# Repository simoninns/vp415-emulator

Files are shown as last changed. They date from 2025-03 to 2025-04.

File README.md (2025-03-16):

# VP415 Emulator
## Project status
This is a purely experimental repo and is not for any kind of production use.

## Disclaimer
Whatever is in this repository is fiction and should not be taken seriously. All similarities with real world designs and coding was not intentional

## Author
VP415 Emulator is designed and maintained by Simon Inns.

## Software License (GPLv3)

    This is free software: you can redistribute it and/or modify
    it under the terms of the GNU General Public License as published by
    the Free Software Foundation, either version 3 of the License, or
    (at your option) any later version.

    This software is distributed in the hope that it will be useful,
    but WITHOUT ANY WARRANTY; without even the implied warranty of
    MERCHANTABILITY or FITNESS FOR A PARTICULAR PURPOSE.  See the
    GNU General Public License for more details.

    You should have received a copy of the GNU General Public License
    along with this program.  If not, see <http://www.gnu.org/licenses/>.

## Hardware License (Creative Commons BY-SA 4.0)
Please see the following link for details: https://creativecommons.org/licenses/by-sa/4.0/

You are free to:

Share - copy and redistribute the material in any medium or format
Adapt - remix, transform, and build upon the material
for any purpose, even commercially.

This license is acceptable for Free Cultural Works.

The licensor cannot revoke these freedoms as long as you follow the license terms.

Under the following terms:

Attribution - You must give appropriate credit, provide a link to the license, and indicate if changes were made. You may do so in any reasonable manner, but not in any way that suggests the licensor endorses you or your use.

ShareAlike - If you remix, transform, or build upon the material, you must distribute your contributions under the same license as the original.

No additional restrictions - You may not apply legal terms or technological measures that legally restrict others from doing anything the license permits.

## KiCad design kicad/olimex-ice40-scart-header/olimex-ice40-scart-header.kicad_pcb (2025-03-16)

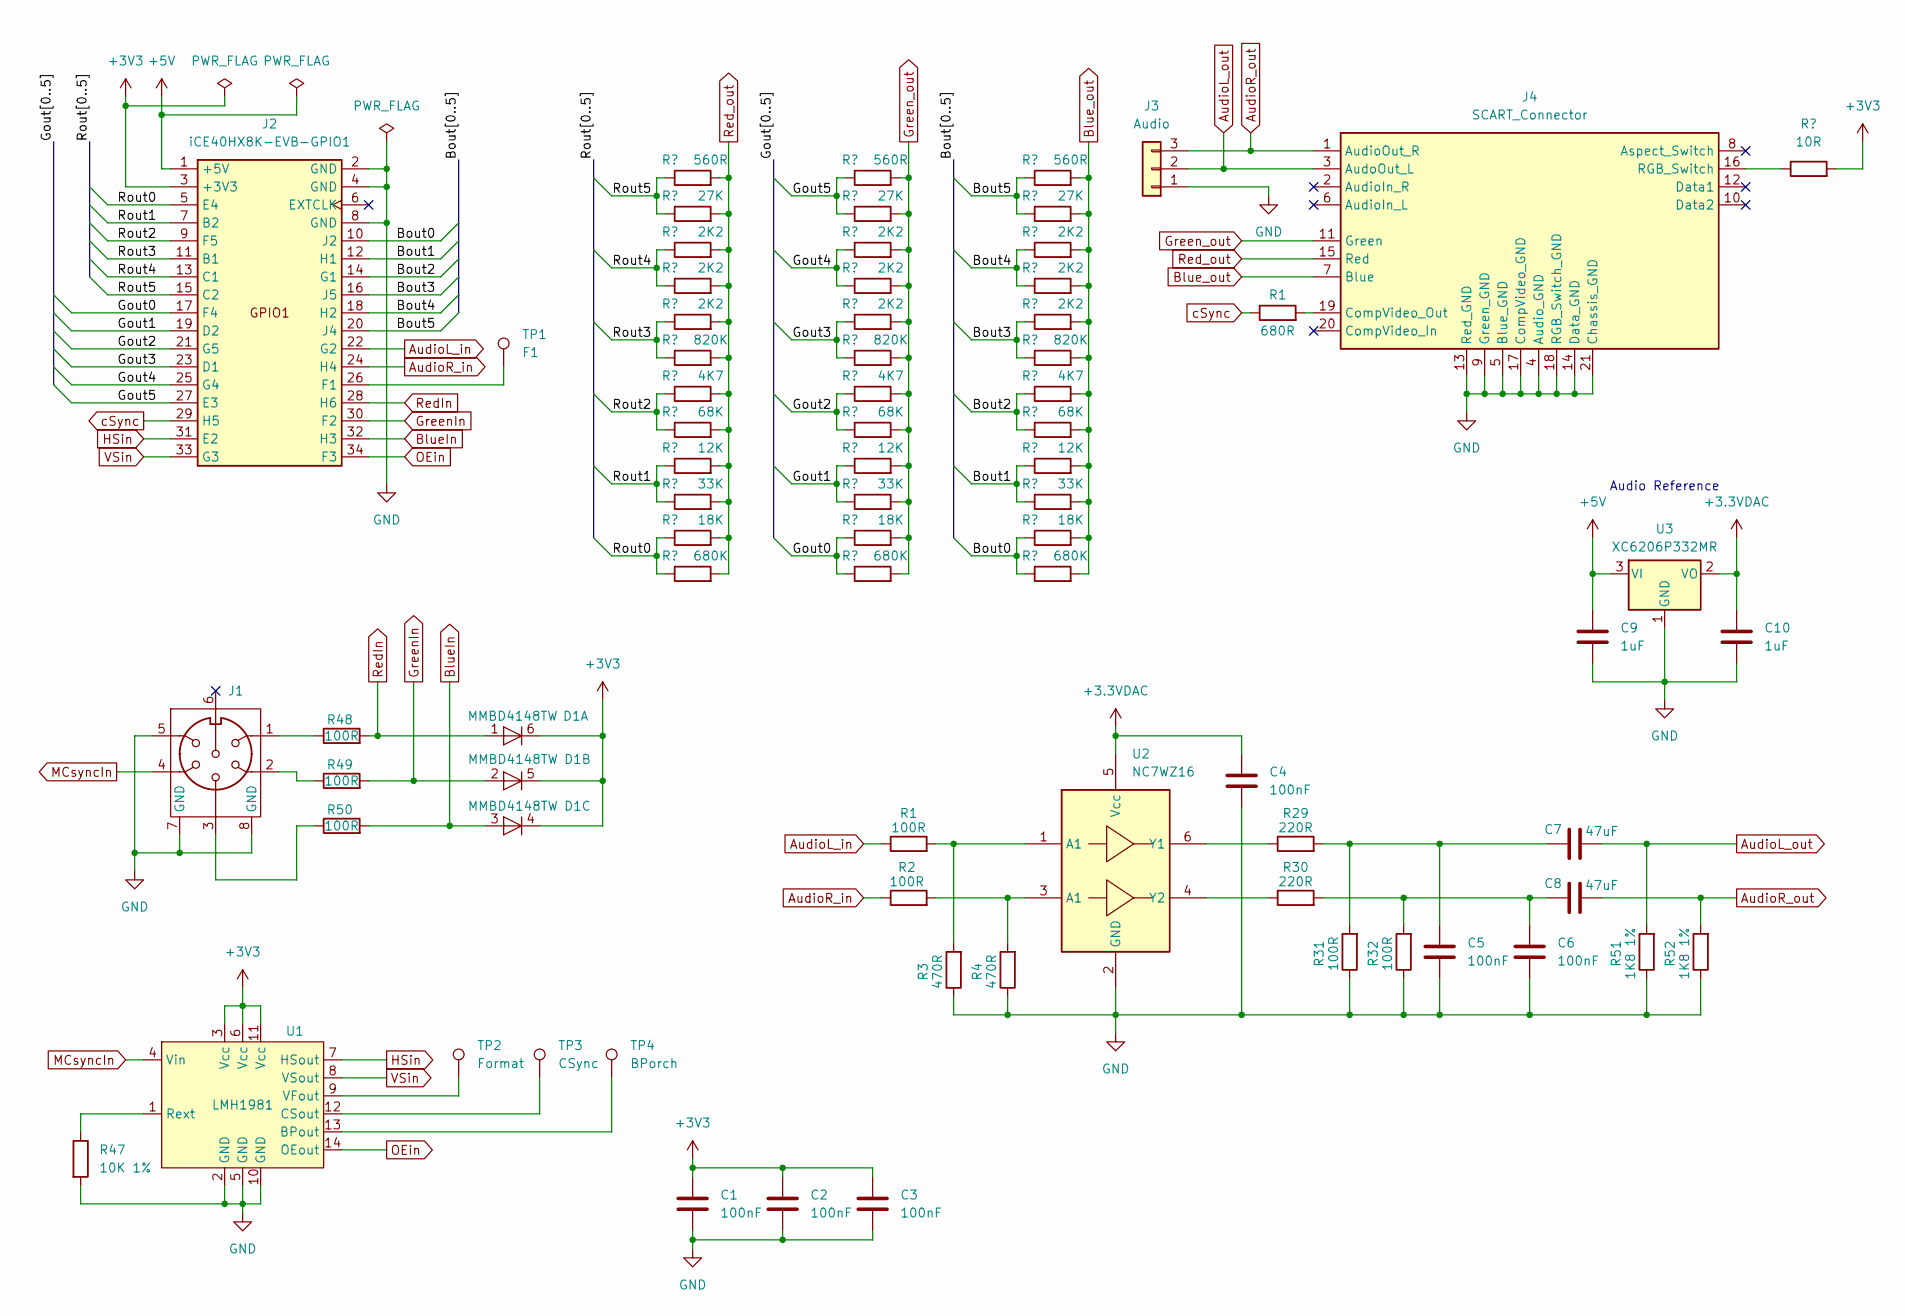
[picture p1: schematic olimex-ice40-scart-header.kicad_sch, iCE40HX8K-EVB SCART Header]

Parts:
C1, C2, C3, C4, C5, C6: 100nF; C_0603_1608Metric_Pad1.08x0.95mm_HandSolder
C7, C8: 47uF; C_0603_1608Metric_Pad1.08x0.95mm_HandSolder
C9, C10: 1uF; C_0603_1608Metric_Pad1.08x0.95mm_HandSolder
D1: MMBD4148TW; SOT-363_SC-70-6
J1: 6P DIN Socket RS Pro
J2: iCE40HX8K-EVB-GPIO1; IDC-Header_2x17_P2.54mm_Horizontal
J3: Audio; PinHeader_1x03_P2.54mm_Vertical
J4: SCART_Connector; HSM_C0381-21RYATB0R
R1: 680R; R_0603_1608Metric_Pad0.98x0.95mm_HandSolder
R2, R31, R32, R48, R49, R50: 100R; R_0603_1608Metric_Pad0.98x0.95mm_HandSolder
R3, R4: 470R; R_0603_1608Metric_Pad0.98x0.95mm_HandSolder
R5, R17, R33: 560R; R_0603_1608Metric_Pad0.98x0.95mm_HandSolder
R6, R18, R34: 27K; R_0603_1608Metric_Pad0.98x0.95mm_HandSolder
R7, R8, R9, R19, R20, R21, R35, R36, R37: 2K2; R_0603_1608Metric_Pad0.98x0.95mm_HandSolder
R10, R22, R38: 820K; R_0603_1608Metric_Pad0.98x0.95mm_HandSolder
R11, R23, R39: 4K7; R_0603_1608Metric_Pad0.98x0.95mm_HandSolder
R12, R24, R40: 68K; R_0603_1608Metric_Pad0.98x0.95mm_HandSolder
R13, R25, R41: 12K; R_0603_1608Metric_Pad0.98x0.95mm_HandSolder
R14, R26, R42: 33K; R_0603_1608Metric_Pad0.98x0.95mm_HandSolder
R15, R27, R43: 18K; R_0603_1608Metric_Pad0.98x0.95mm_HandSolder
R16, R28, R44: 680K; R_0603_1608Metric_Pad0.98x0.95mm_HandSolder
R29, R30: 220R; R_0603_1608Metric_Pad0.98x0.95mm_HandSolder
R46: 10R; R_0603_1608Metric_Pad0.98x0.95mm_HandSolder
R47: 10K 1%; R_0603_1608Metric_Pad0.98x0.95mm_HandSolder
R51, R52: 1K8 1%; R_0603_1608Metric_Pad0.98x0.95mm_HandSolder
TP1: F1; TestPoint_Pad_1.5x1.5mm
TP2: Format; TestPoint_Pad_1.5x1.5mm
TP3: CSync; TestPoint_Pad_1.5x1.5mm
TP4: BPorch; TestPoint_Pad_1.5x1.5mm
U1: LMH1981; TSSOP-14_4.4x5mm_P0.65mm
U2: NC7WZ16; SOT-363_SC-70-6_Handsoldering
U3: XC6206P332MR; SOT-23-3

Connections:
+3.3VDAC: C4.1, C10.1, U2.5 (Vcc), U3.2 (VO)
+3V3: C1.1, C2.1, C3.1, D1.4 (K), D1.5 (K), D1.6 (K), J2.3 (+3V3), R46.2, U1.3 (Vcc), U1.6 (Vcc), U1.11 (Vcc)
+5V: C9.1, J2.1 (+5V), U3.3 (VI)
/Bout0: J2.10 (J2), R43.1, R44.1
/Bout1: J2.12 (H1), R41.1, R42.1
/Bout2: J2.14 (G1), R39.1, R40.1
/Bout3: J2.16 (J5), R37.1, R38.1
/Bout4: J2.18 (H2), R35.1, R36.1
/Bout5: J2.20 (J4), R33.1, R34.1
/Gout0: J2.17 (F4), R27.1, R28.1
/Gout1: J2.19 (D2), R25.1, R26.1
/Gout2: J2.21 (G5), R23.1, R24.1
/Gout3: J2.23 (D1), R21.1, R22.1
/Gout4: J2.25 (G4), R19.1, R20.1
/Gout5: J2.27 (E3), R17.1, R18.1
/Rout0: J2.5 (E4), R15.1, R16.1
/Rout1: J2.7 (B2), R13.1, R14.1
/Rout2: J2.9 (F5), R11.1, R12.1
/Rout3: J2.11 (B1), R9.1, R10.1
/Rout4: J2.13 (C1), R7.1, R8.1
/Rout5: J2.15 (C2), R5.1, R6.1
AudioL_out: C7.2, J3.2, J4.3 (AudoOut_L), R51.2
AudioR_in: J2.24 (H4), R2.1
AudioR_out: C8.2, J3.3, J4.1 (AudioOut_R), R52.2
BlueIn: D1.3 (A), J2.32 (H3), R50.2
Blue_out: J4.7 (Blue), R33.2, R34.2, R35.2, R36.2, R37.2, R38.2, R39.2, R40.2, R41.2, R42.2, R43.2, R44.2
GND: C1.2, C2.2, C3.2, C4.2, C5.2, C6.2, C9.2, C10.2, J1.5, J1.7 (GND), J1.8 (GND), J2.2 (GND), J2.4 (GND), J2.8 (GND), J3.1, J4.4 (Audio_GND), J4.5 (Blue_GND), J4.9 (Green_GND), J4.13 (Red_GND), J4.14 (Data_GND), J4.17 (CompVideo_GND), J4.18 (RGB_Switch_GND), J4.21 (Chassis_GND), R3.1, R4.1, R31.1, R32.1, R47.2, R51.1, R52.1, U1.2 (GND), U1.5 (GND), U1.10 (GND), U2.2 (GND), U3.1 (GND)
GreenIn: D1.2 (A), J2.30 (F2), R49.2
Green_out: J4.11 (Green), R17.2, R18.2, R19.2, R20.2, R21.2, R22.2, R23.2, R24.2, R25.2, R26.2, R27.2, R28.2
HSin: J2.31 (E2), U1.7 (HSout)
MCsyncIn: J1.4, U1.4 (Vin)
unnamed: C5.1, C7.1, R29.2, R31.2
unnamed: C6.1, C8.1, R30.2, R32.2
unnamed: J1.1, R48.1
unnamed: J1.2, R49.1
unnamed: J1.3, R50.1
unnamed: J2.26 (F1), TP1.1
unnamed: J4.16 (RGB_Switch), R46.1
unnamed: R2.2, R4.2, U2.3 (A1)
unnamed: TP4.1, U1.13 (BPout)
unnamed: TP3.1, U1.12 (CSout)
unnamed: R47.1, U1.1 (Rext)
unnamed: TP2.1, U1.9 (VFout)
unnamed: R29.1, U2.6 (Y1)
unnamed: R30.1, U2.4 (Y2)
OEin: J2.34 (F3), U1.14 (OEout)
RedIn: D1.1 (A), J2.28 (H6), R48.2
Red_out: J4.15 (Red), R5.2, R6.2, R7.2, R8.2, R9.2, R10.2, R11.2, R12.2, R13.2, R14.2, R15.2, R16.2
VSin: J2.33 (G3), U1.8 (VSout)

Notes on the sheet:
Audio Reference

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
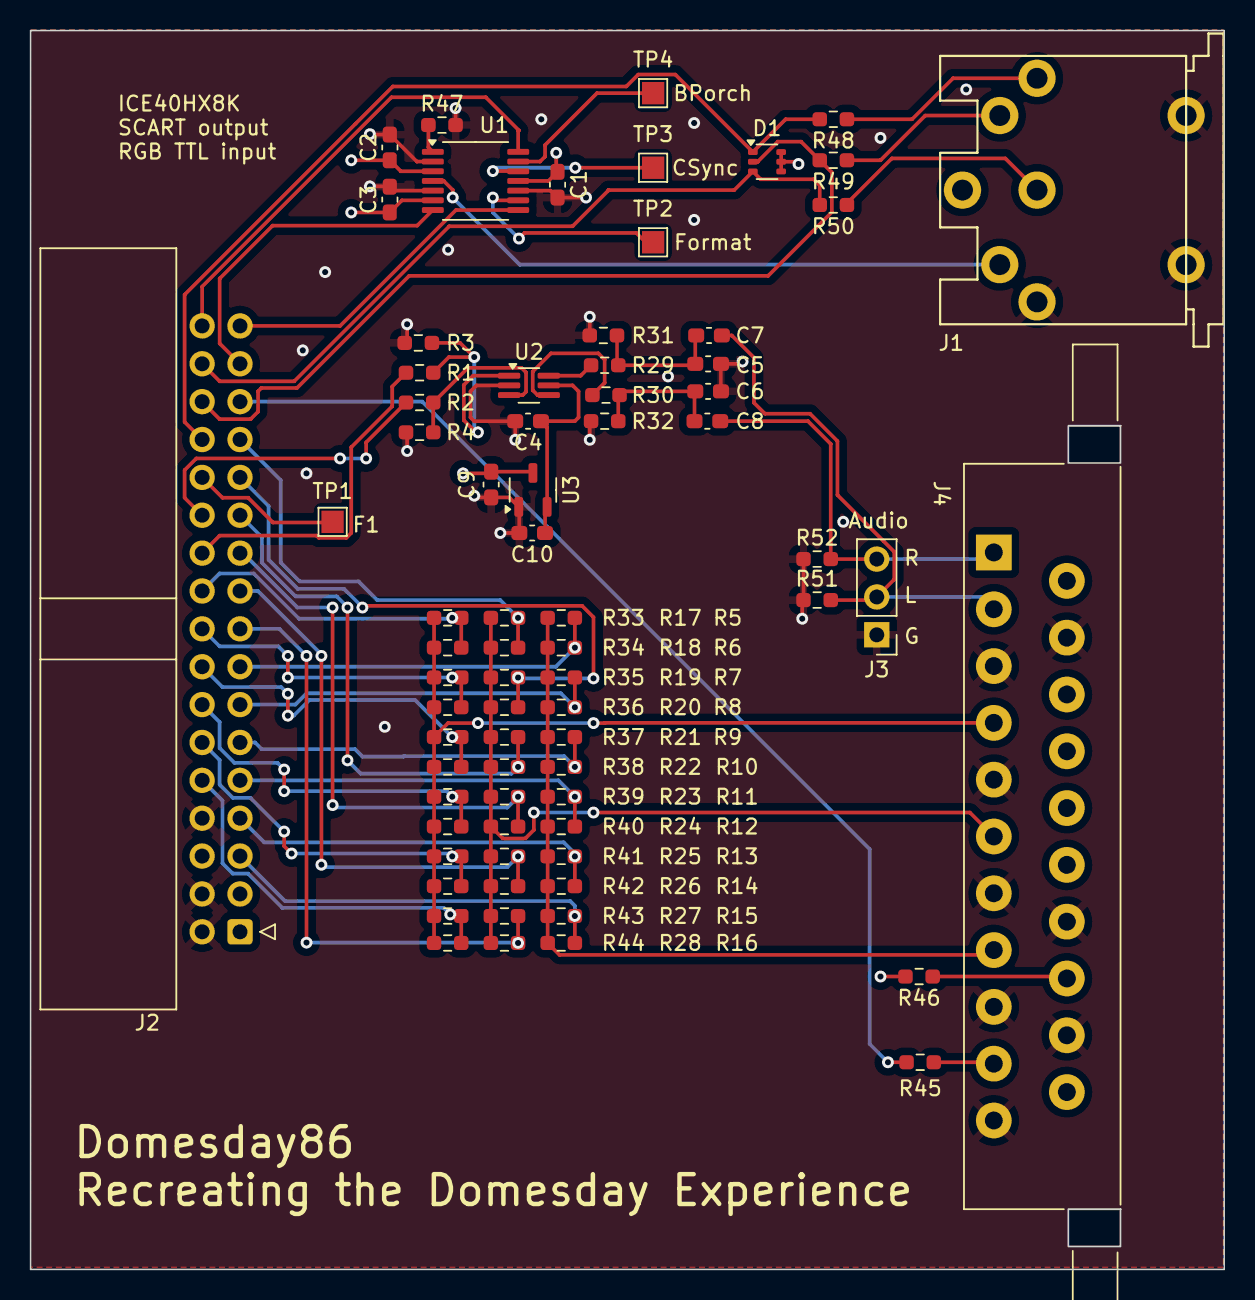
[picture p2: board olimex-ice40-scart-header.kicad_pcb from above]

Board: 4 copper layers, 80.1 x 83.1 mm, 74 parts (0 on the bottom side), 53 nets.

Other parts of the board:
R45: 680R; R_0603_1608Metric_Pad0.98x0.95mm_HandSolder

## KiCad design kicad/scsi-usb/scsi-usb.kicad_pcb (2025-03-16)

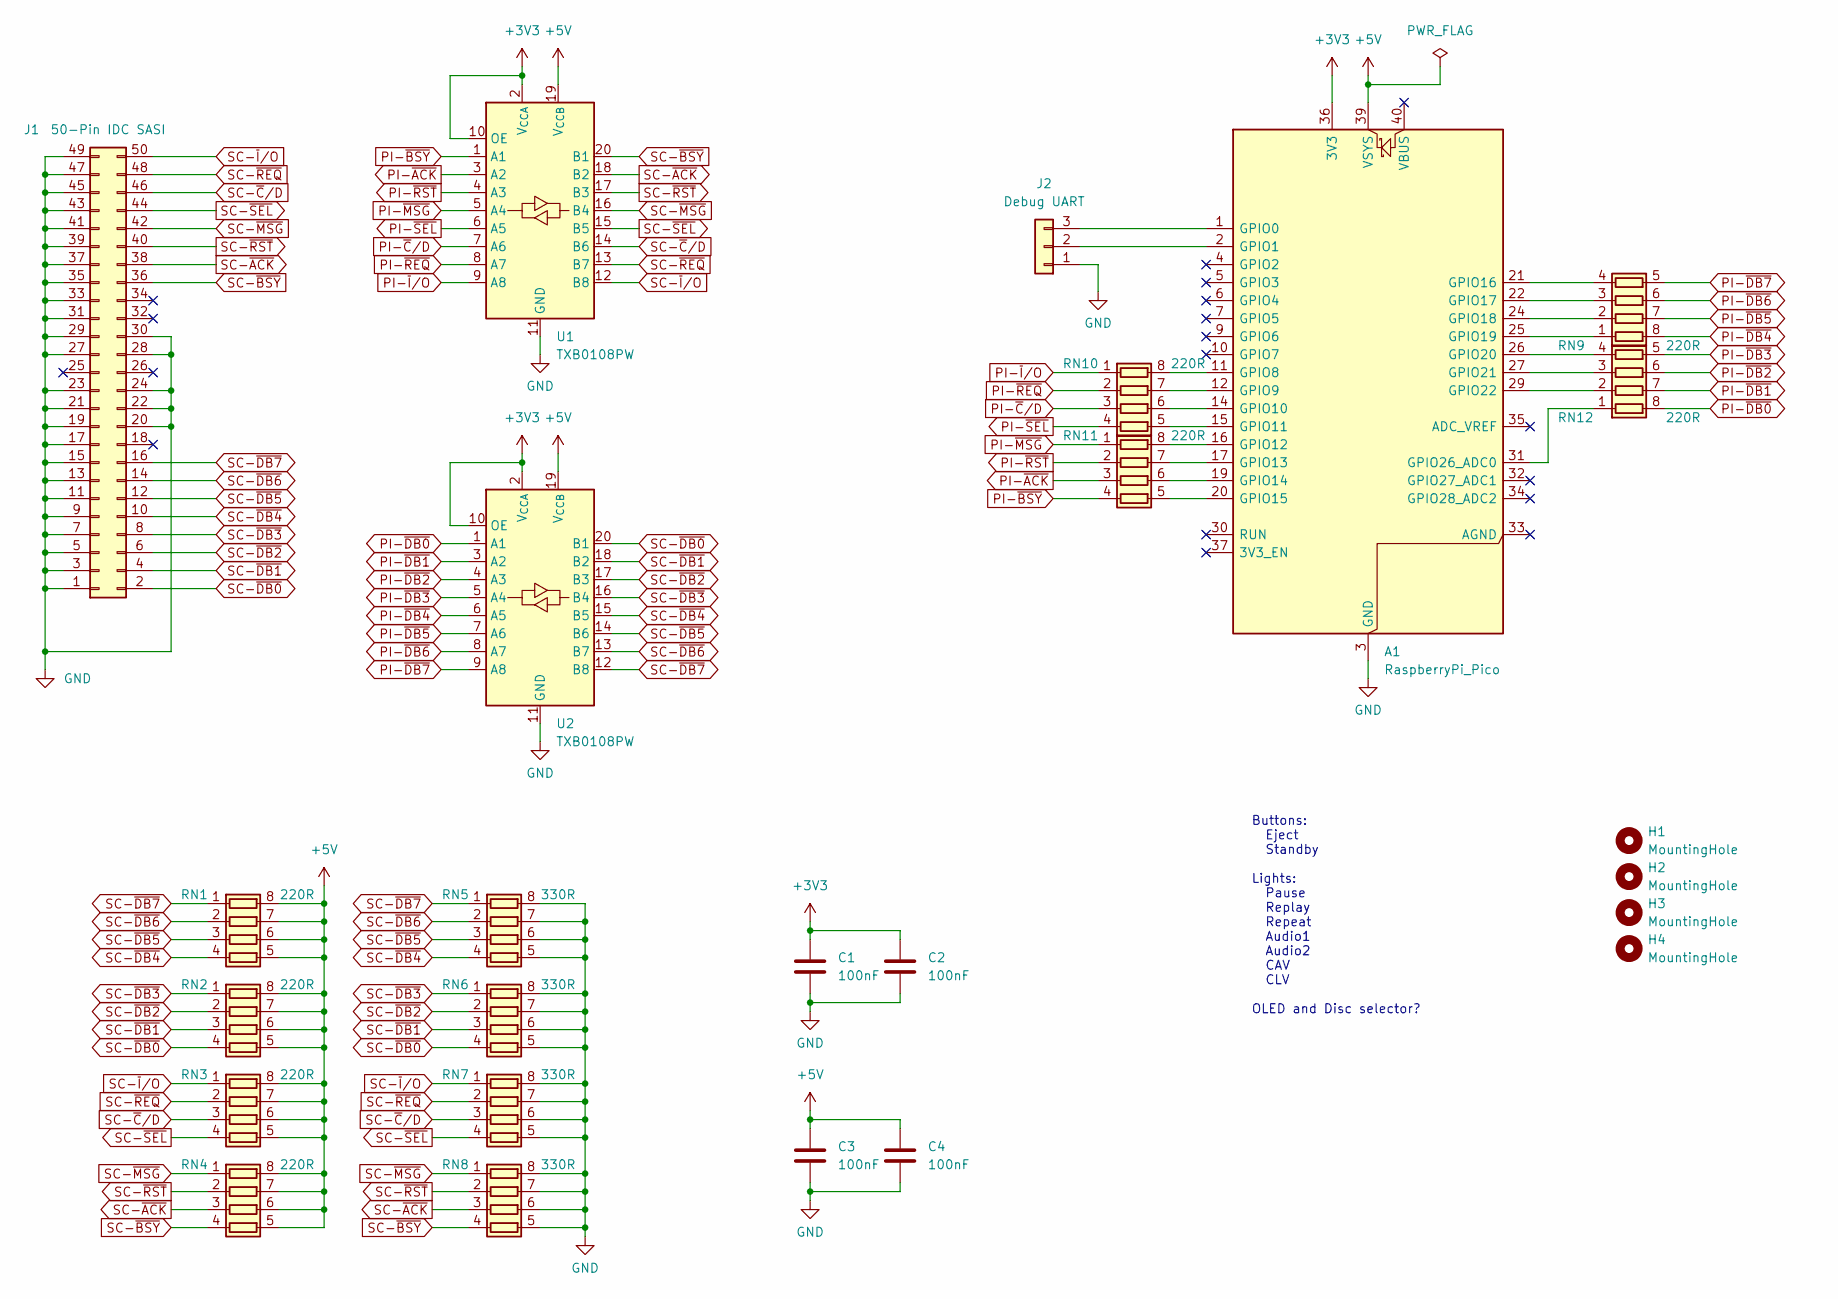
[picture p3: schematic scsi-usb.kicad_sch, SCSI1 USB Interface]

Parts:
A1: RaspberryPi_Pico; RaspberryPi_Pico_Common
C1, C2, C3, C4: 100nF; C_0805_2012Metric
H1, H2, H3, H4: MountingHole; MountingHole_3.2mm_M3
J1: 50-Pin IDC SASI; IDC-Header_2x25_P2.54mm_Latch_Horizontal
J2: Debug UART; PinHeader_1x03_P2.54mm_Vertical
RN1, RN2, RN3, RN4, RN9, RN10, RN11, RN12: 220R; R_Array_Convex_4x1206
RN5, RN6, RN7, RN8: 330R; R_Array_Convex_4x1206
U1, U2: TXB0108PW; TSSOP-20_4.4x6.5mm_P0.65mm

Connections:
+3V3: A1.36 (3V3), C1.1, C2.1, U1.2 (V_{CCA}), U1.10 (OE), U2.2 (V_{CCA}), U2.10 (OE)
+5V: A1.39 (VSYS), C3.1, C4.1, RN1.5 (R4.2), RN1.6 (R3.2), RN1.7 (R2.2), RN1.8 (R1.2), RN2.5 (R4.2), RN2.6 (R3.2), RN2.7 (R2.2), RN2.8 (R1.2), RN3.5 (R4.2), RN3.6 (R3.2), RN3.7 (R2.2), RN3.8 (R1.2), RN4.5 (R4.2), RN4.6 (R3.2), RN4.7 (R2.2), RN4.8 (R1.2), U1.19 (V_{CCB}), U2.19 (V_{CCB})
GND: A1.3 (GND), A1.8 (GND), A1.13 (GND), A1.18 (GND), A1.23 (GND), A1.28 (GND), A1.38 (GND), C1.2, C2.2, C3.2, C4.2, J1.1, J1.3, J1.5, J1.7, J1.9, J1.11, J1.13, J1.15, J1.17, J1.19, J1.20, J1.21, J1.22, J1.23, J1.24, J1.27, J1.28, J1.29, J1.30, J1.31, J1.33, J1.35, J1.37, J1.39, J1.41, J1.43, J1.45, J1.47, J1.49, J2.1, RN5.5 (R4.2), RN5.6 (R3.2), RN5.7 (R2.2), RN5.8 (R1.2), RN6.5 (R4.2), RN6.6 (R3.2), RN6.7 (R2.2), RN6.8 (R1.2), RN7.5 (R4.2), RN7.6 (R3.2), RN7.7 (R2.2), RN7.8 (R1.2), RN8.5 (R4.2), RN8.6 (R3.2), RN8.7 (R2.2), RN8.8 (R1.2), U1.11 (GND), U2.11 (GND)
unnamed: A1.1 (GPIO0), J2.3
unnamed: A1.2 (GPIO1), J2.2
unnamed: A1.11 (GPIO8), RN10.8 (R1.2)
unnamed: A1.12 (GPIO9), RN10.7 (R2.2)
unnamed: A1.14 (GPIO10), RN10.6 (R3.2)
unnamed: A1.15 (GPIO11), RN10.5 (R4.2)
unnamed: A1.16 (GPIO12), RN11.8 (R1.2)
unnamed: A1.17 (GPIO13), RN11.7 (R2.2)
unnamed: A1.19 (GPIO14), RN11.6 (R3.2)
unnamed: A1.20 (GPIO15), RN11.5 (R4.2)
unnamed: A1.21 (GPIO16), RN9.4 (R4.1)
unnamed: A1.22 (GPIO17), RN9.3 (R3.1)
unnamed: A1.24 (GPIO18), RN9.2 (R2.1)
unnamed: A1.25 (GPIO19), RN9.1 (R1.1)
unnamed: A1.26 (GPIO20), RN12.4 (R4.1)
unnamed: A1.27 (GPIO21), RN12.3 (R3.1)
unnamed: A1.29 (GPIO22), RN12.2 (R2.1)
unnamed: A1.31 (GPIO26_ADC0), RN12.1 (R1.1)
PI-~ACK: RN11.3 (R3.1), U1.3 (A2)
PI-~BSY: RN11.4 (R4.1), U1.1 (A1)
PI-~C/D: RN10.3 (R3.1), U1.7 (A6)
PI-~DB0: RN12.8 (R1.2), U2.1 (A1)
PI-~DB1: RN12.7 (R2.2), U2.3 (A2)
PI-~DB2: RN12.6 (R3.2), U2.4 (A3)
PI-~DB3: RN12.5 (R4.2), U2.5 (A4)
PI-~DB4: RN9.8 (R1.2), U2.6 (A5)
PI-~DB5: RN9.7 (R2.2), U2.7 (A6)
PI-~DB6: RN9.6 (R3.2), U2.8 (A7)
PI-~DB7: RN9.5 (R4.2), U2.9 (A8)
PI-~I/O: RN10.1 (R1.1), U1.9 (A8)
PI-~MSG: RN11.1 (R1.1), U1.5 (A4)
PI-~REQ: RN10.2 (R2.1), U1.8 (A7)
PI-~RST: RN11.2 (R2.1), U1.4 (A3)
PI-~SEL: RN10.4 (R4.1), U1.6 (A5)
SC-~ACK: J1.38, RN4.3 (R3.1), RN8.3 (R3.1), U1.18 (B2)
SC-~BSY: J1.36, RN4.4 (R4.1), RN8.4 (R4.1), U1.20 (B1)
SC-~C/D: J1.46, RN3.3 (R3.1), RN7.3 (R3.1), U1.14 (B6)
SC-~DB0: J1.2, RN2.4 (R4.1), RN6.4 (R4.1), U2.20 (B1)
SC-~DB1: J1.4, RN2.3 (R3.1), RN6.3 (R3.1), U2.18 (B2)
SC-~DB2: J1.6, RN2.2 (R2.1), RN6.2 (R2.1), U2.17 (B3)
SC-~DB3: J1.8, RN2.1 (R1.1), RN6.1 (R1.1), U2.16 (B4)
SC-~DB4: J1.10, RN1.4 (R4.1), RN5.4 (R4.1), U2.15 (B5)
SC-~DB5: J1.12, RN1.3 (R3.1), RN5.3 (R3.1), U2.14 (B6)
SC-~DB6: J1.14, RN1.2 (R2.1), RN5.2 (R2.1), U2.13 (B7)
SC-~DB7: J1.16, RN1.1 (R1.1), RN5.1 (R1.1), U2.12 (B8)
SC-~I/O: J1.50, RN3.1 (R1.1), RN7.1 (R1.1), U1.12 (B8)
SC-~MSG: J1.42, RN4.1 (R1.1), RN8.1 (R1.1), U1.16 (B4)
SC-~REQ: J1.48, RN3.2 (R2.1), RN7.2 (R2.1), U1.13 (B7)
SC-~RST: J1.40, RN4.2 (R2.1), RN8.2 (R2.1), U1.17 (B3)
SC-~SEL: J1.44, RN3.4 (R4.1), RN7.4 (R4.1), U1.15 (B5)

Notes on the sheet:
Buttons: Eject Standby Lights: Pause Replay Repeat Audio1 Audio2 CAV CLV OLED and Disc selector?

Board: 2 copper layers, 25 parts (0 on the bottom side), 53 nets, no tracks yet.

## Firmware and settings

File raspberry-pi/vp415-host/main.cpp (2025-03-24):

/************************************************************************

    main.cpp

    VP415-host - A host application for the VP415 Emulator
    VP415-Emulator
    Copyright (C) 2025 Simon Inns

    This file is part of VP415-Emulator.

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
    Email: simon.inns@gmail.com

************************************************************************/

#include <QApplication>
#include <QDebug>
#include <QtGlobal>
#include <QCommandLineParser>

#include "mainwindow.h"

int main(int argc, char *argv[]) {
    QApplication app(argc, argv);

    // Set application name and version
    QCoreApplication::setApplicationName("vp415-host");
    QCoreApplication::setApplicationVersion(
            QString("Branch: %1 / Commit: %2").arg(APP_BRANCH, APP_COMMIT));
    QCoreApplication::setOrganizationDomain("domesday86.com");

    // Set up the command line parser
    QCommandLineParser parser;
    parser.setApplicationDescription(
            "vp415-host - VP415 Emulator host\n"
            "\n"
            "(c)2025 Simon Inns\n"
            "GPLv3 Open-Source - github: https://github.com/simoninns/efm-tools");
    parser.addHelpOption();
    parser.addVersionOption();

    // Add an option for specifying the JSON file of the initial disc to open
    QCommandLineOption jsonFileOption(QStringList() << "j" << "json",
        QCoreApplication::translate("main", "Specify the JSON file of the initial disc to open"),
        QCoreApplication::translate("main", "file"));
    parser.addOption(jsonFileOption);

    // -- Positional arguments --
    parser.addPositionalArgument("serialport",
        QCoreApplication::translate("main", "Specify serial port device to use"));
    
    // Process the command line options and arguments given by the user
    parser.process(app);

    // Get the JSON file argument from the parser
    QString jsonFilename = parser.value(jsonFileOption);

    // Get the filename arguments from the parser
    QString serialDeviceName;
    QStringList positionalArguments = parser.positionalArguments();

    if (positionalArguments.count() != 1) {
        qWarning() << "You must specify the serial device name";
        return 1;
    }
    serialDeviceName = positionalArguments.at(0);

    // Get on with the main window
    MainWindow mainWindow(nullptr, serialDeviceName, jsonFilename);
    mainWindow.show();

    return app.exec();
}

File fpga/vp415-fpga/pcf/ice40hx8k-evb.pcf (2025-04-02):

# VP415-Emulator FPGA PCF file
# Based on the Olimex iCE40HX8K-EVB board

## 100MHz System clock (unused at the moment)
# set_io -nowarn clock100Mhz J3

## Buttons
set_io -nowarn buttons[0] K11
set_io -nowarn buttons[1] P13

## LEDs
set_io -nowarn leds[0] M12
set_io -nowarn leds[1] R16

## Samsung K6R4016V1D-TC10 512K SRAM (on-board)
set_io -nowarn SRAM0_nCS T6
set_io -nowarn SRAM0_nOE L9
set_io -nowarn SRAM0_nWE T7
set_io -nowarn SRAM0_A[0] N6
set_io -nowarn SRAM0_A[1] T1
set_io -nowarn SRAM0_A[2] P4
set_io -nowarn SRAM0_A[3] R2
set_io -nowarn SRAM0_A[4] N5
set_io -nowarn SRAM0_A[5] T2
set_io -nowarn SRAM0_A[6] P5
set_io -nowarn SRAM0_A[7] R3
set_io -nowarn SRAM0_A[8] R5
set_io -nowarn SRAM0_A[9] T3
set_io -nowarn SRAM0_A[10] R4
set_io -nowarn SRAM0_A[11] M7
set_io -nowarn SRAM0_A[12] N7
set_io -nowarn SRAM0_A[13] P6
set_io -nowarn SRAM0_A[14] M8
set_io -nowarn SRAM0_A[15] T5
set_io -nowarn SRAM0_A[16] R6
set_io -nowarn SRAM0_A[17] P8
set_io -nowarn SRAM0_D[0] T8
set_io -nowarn SRAM0_D[1] P7
set_io -nowarn SRAM0_D[2] N9
set_io -nowarn SRAM0_D[3] T9
set_io -nowarn SRAM0_D[4] M9
set_io -nowarn SRAM0_D[5] R9
set_io -nowarn SRAM0_D[6] K9
set_io -nowarn SRAM0_D[7] P9
set_io -nowarn SRAM0_D[8] R10
set_io -nowarn SRAM0_D[9] L10
set_io -nowarn SRAM0_D[10] P10
set_io -nowarn SRAM0_D[11] N10
set_io -nowarn SRAM0_D[12] T10
set_io -nowarn SRAM0_D[13] T11
set_io -nowarn SRAM0_D[14] T15
set_io -nowarn SRAM0_D[15] T14

## GPIO1 (34 pin right-angle IDC)
## SCART RGB666
set_io -nowarn rgb_scart_666[12] E4 # Red LSB
set_io -nowarn rgb_scart_666[13] B2
set_io -nowarn rgb_scart_666[14] F5
set_io -nowarn rgb_scart_666[15] B1
set_io -nowarn rgb_scart_666[16] C1
set_io -nowarn rgb_scart_666[17] C2 # Red MSB

set_io -nowarn rgb_scart_666[6] F4 # Green LSB
set_io -nowarn rgb_scart_666[7] D2
set_io -nowarn rgb_scart_666[8] G5
set_io -nowarn rgb_scart_666[9] D1
set_io -nowarn rgb_scart_666[10] G4
set_io -nowarn rgb_scart_666[11] E3 # Green MSB

set_io -nowarn rgb_scart_666[0] J2 # Blue LSB
set_io -nowarn rgb_scart_666[1] H1
set_io -nowarn rgb_scart_666[2] G1
set_io -nowarn rgb_scart_666[3] J5
set_io -nowarn rgb_scart_666[4] H2
set_io -nowarn rgb_scart_666[5] J4 # Blue MSB

set_io -nowarn csync_scart H5

set_io -nowarn gpio1_22 G2
set_io -nowarn gpio1_24 H4
set_io -nowarn gpio1_26 F1
set_io -nowarn gpio1_28 H6
set_io -nowarn gpio1_30 F2
set_io -nowarn gpio1_31 E2
set_io -nowarn gpio1_32 H3
set_io -nowarn gpio1_33 G3
set_io -nowarn gpio1_34 F3

## EXT2 Temp TTL RGB in
set_io -nowarn rgb_aiv_111[2] B6 # Red
set_io -nowarn rgb_aiv_111[1] C6 # Green
set_io -nowarn rgb_aiv_111[0] D7 # Blue
set_io -nowarn aiv_csync A6
# set_io -nowarn aiv_vsyncIn D6
# set_io -nowarn aiv_csyncIn A5

## EXT3 40-pin header to Raspberry Pi GPIO header
set_io -nowarn pi_gpio[2]  M15
set_io -nowarn pi_gpio[3]  J11
set_io -nowarn pi_gpio[4]  E14
set_io -nowarn pi_gpio[14] L16
set_io -nowarn pi_gpio[15] F11
set_io -nowarn pi_gpio[17] K13
set_io -nowarn pi_gpio[18] D15
set_io -nowarn pi_gpio[27] K14
set_io -nowarn pi_gpio[22] F12
set_io -nowarn pi_gpio[23] J15
set_io -nowarn pi_gpio[24] F14
set_io -nowarn pi_gpio[10] K15
set_io -nowarn pi_gpio[9]  G12
set_io -nowarn pi_gpio[25] K16
set_io -nowarn pi_gpio[11] D16
set_io -nowarn pi_gpio[8]  J14
set_io -nowarn pi_gpio[7]  G13
set_io -nowarn pi_gpio[0]  J12
set_io -nowarn pi_gpio[1]  E16
set_io -nowarn pi_gpio[5]  J13
set_io -nowarn pi_gpio[6]  G14
set_io -nowarn pi_gpio[12] J16
set_io -nowarn pi_gpio[13] F15
set_io -nowarn pi_gpio[19] H13
set_io -nowarn pi_gpio[16] G11
set_io -nowarn pi_gpio[26] H11
set_io -nowarn pi_gpio[20] F16
set_io -nowarn pi_gpio[21] H16

## EXT4 - PicoScope 16-bit Data analysis connector
set_io -nowarn picoScope[0] N4
set_io -nowarn picoScope[1] M5
set_io -nowarn picoScope[2] P2
set_io -nowarn picoScope[3] P1
set_io -nowarn picoScope[4] N3
set_io -nowarn picoScope[5] R1
set_io -nowarn picoScope[6] M4
set_io -nowarn picoScope[7] L5
set_io -nowarn picoScope[8] M3
set_io -nowarn picoScope[9] N2
set_io -nowarn picoScope[10] L7
set_io -nowarn picoScope[11] K5
set_io -nowarn picoScope[12] L3
set_io -nowarn picoScope[13] M6
set_io -nowarn picoScope[14] M2
set_io -nowarn picoScope[15] L6

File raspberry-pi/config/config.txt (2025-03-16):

# VP415-Emualator Raspberry Pi 5 Configuration
# /boot/firmware/config.txt

# Enable interlaced PAL video output via GPIO (DPI)
# Note: 720x576 @ 13.5 MHz according to ITU-R BT.601
dtoverlay=vc4-kms-dpi-generic
dtparam=clock-frequency=13500000
dtparam=hactive=720,hfp=12,hsync=64,hbp=68
dtparam=vactive=576,vfp=5,vsync=5,vbp=39
dtparam=interlaced
dtparam=hsync-invert,vsync-invert

# Enable audio (loads snd_bcm2835)
dtparam=audio=on

# Automatically load overlays for detected cameras
camera_auto_detect=1

# Automatically load overlays for detected DSI displays
display_auto_detect=1

# Automatically load initramfs files, if found
auto_initramfs=1

# Enable DRM VC4 V3D driver
dtoverlay=vc4-kms-v3d
max_framebuffers=2

# Don't have the firmware create an initial video= setting in cmdline.txt.
# Use the kernel's default instead.
disable_fw_kms_setup=1

# Run in 64-bit mode
arm_64bit=1

# Disable compensation for displays with overscan
disable_overscan=1

# Run as fast as firmware / board allows
arm_boost=1

[cm4]
# Enable host mode on the 2711 built-in XHCI USB controller.
# This line should be removed if the legacy DWC2 controller is required
# (e.g. for USB device mode) or if USB support is not required.
otg_mode=1

[all]

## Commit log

2025-03-16 Pushing project files to github
    [config.txt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]
2025-03-16 Added pico footprint kicad submodule to library
2025-03-16 Added build environment for raspberry pico sasi2usb
2025-03-16 Basic pico project now compiling and working on the Pico2
2025-03-22 Added basic serial port handing to the Qt GUI app
    [scsi-usb.kicad_sch]
2025-03-23 Added some basic low-level communciation between the Pico and the Pi5
2025-03-24 Added basic commands from pico to host to get to bus free state
2025-03-27 Working hsync separator code
    [olimex-ice40-scart-header.kicad_sch]
2025-03-28 Changed RGB input stage for better noise performance and included a sync regeneration circuit feeding the FPGA
    [audio_filter.kicad_sch, olimex-ice40-scart-header.kicad_sch, rgb_dac.kicad_sch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]
2025-03-28 Added csync passthru to FPGA for dev purposes
    [olimex-ice40-scart-header.kicad_sch, rgb_dac.kicad_sch, rgb_input.kicad_sch]
2025-03-29 Changed RGB input design again
    [olimex-ice40-scart-header.kicad_sch, rgb_input.kicad_sch]
2025-03-29 Added hsync recovery
    [rgb_input.kicad_sch]
2025-03-30 Added basis of new FPGA code - not working yet
    [framebuffer.v, ice40hx8k-evb.pcf]
2025-03-30 Fixed some of the .v headers with correct information
    [framebuffer.v]
2025-04-01 Added basic framebuffer test code project
2025-04-01 Added framebuffer code - doesn't work yet though
    [framebuffer.v]
2025-04-04 Yet another nearly working framebuffer design... this one is almost stable though :)
2025-04-04 Stable testcard through the framebuffer
2025-04-05 Added start of frame flag to the pi video tracking
2025-04-05 Moved Pi start of frame signal generation to the pi pixel tracking module where it should be
2025-04-07 Working framebuffer, but AIV sampling is still out
2025-04-09 Added new test project aivin
    [config.txt]
2025-04-10 New aivin test application added to get the input correct from the AIV - not working yet
    [config.txt]

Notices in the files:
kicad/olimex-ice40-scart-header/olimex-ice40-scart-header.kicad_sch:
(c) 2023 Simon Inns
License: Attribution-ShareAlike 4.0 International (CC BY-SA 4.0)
